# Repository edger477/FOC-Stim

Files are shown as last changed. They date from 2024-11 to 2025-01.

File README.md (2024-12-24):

FOC-Stim is an implementation of the [Restim](https://github.com/diglet48/restim) threephase signal generation algorithm
for the [B-G431B-ESC1](https://www.st.com/en/evaluation-tools/b-g431b-esc1.html) electronic speed controller.

FOC stands for Field Oriented Control, an algorithm for controlling motors, referencing the intended purpose of the hardware.

It utilizes MRAC (model reference adaptive control) to generate consistent current-controlled waveforms
as environment conditions change.

Powered by SimpleFOC.

# Hardware setup

BOM:

* B-G431B-ESC1
* USB cable
* 12v power supply (0.5A minimum)
* 3x transformer (XICON 42TU200-RC suggested)
* 3x inductor (220µH, 1A)
* 3x ceramic caps (10µF 50v)

When selecting an inductor, look for saturation current about 1A and flat inductance-current curve in the datasheet. Some options:
* KEMET SBCP-11HY221H. 80HY or 14HY series also a possibility.
* Fastron 09HVP or 09HCP series.
* Coilcraft RFB0810 or RFB1010 or RFS1317 series
* Coilcraft DR0608-224L, usable if cramped for space

A panel-mount USB micro-B is useful if you want to make this into a nice box.
[USB Micro-B](https://www.sparkfun.com/products/15464)
or [USB B](https://www.sparkfun.com/products/15463).

How to wire:

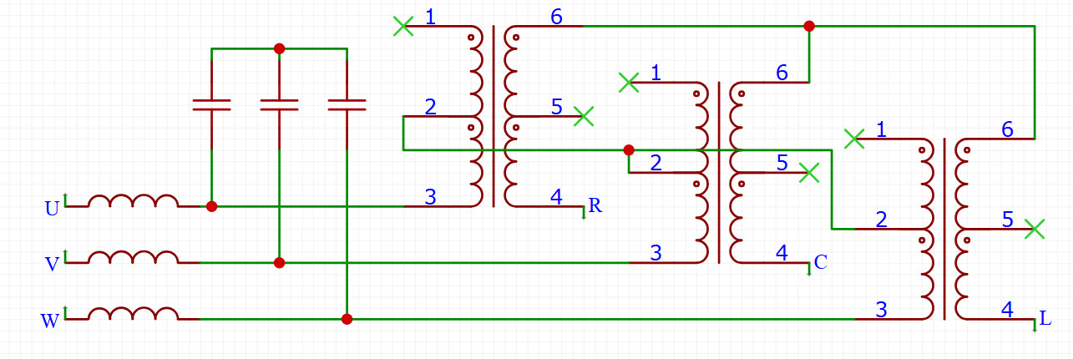
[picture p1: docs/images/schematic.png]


`U`, `V`, `W` are the 3 outputs on the board, with `U` being the one closest to the potentiometer.

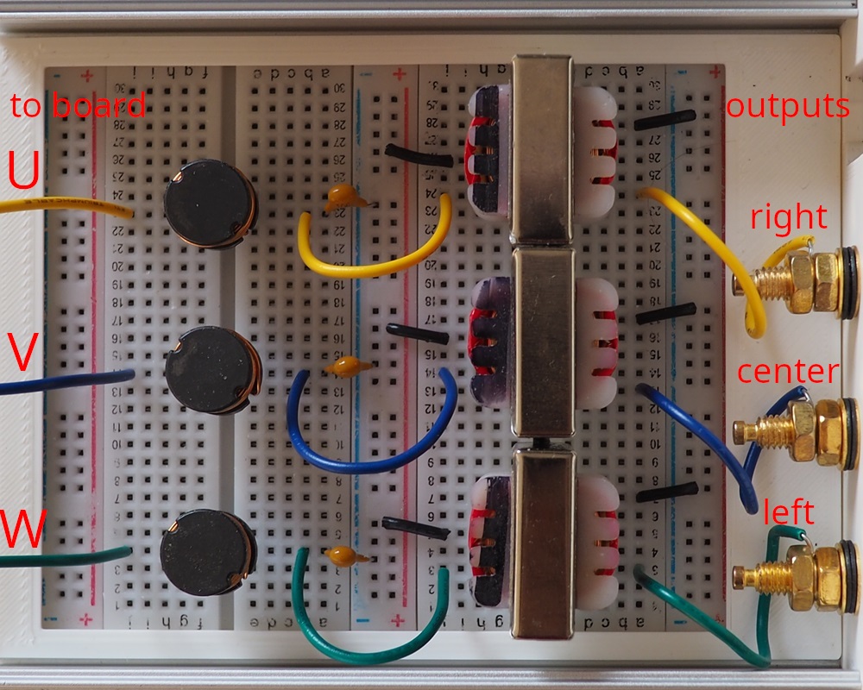
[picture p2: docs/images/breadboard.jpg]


# Software setup

From the factory, the board has a very old ST-link firmware that prevents the usb-serial from working
correctly on some computers. It is highly recommended to update the ST-link firmware using
[STM32CubeProgrammer](https://www.st.com/en/development-tools/stm32cubeprog.html) before proceeding.

Install Visual Studio Code with plugins `platformio` and `teleplot`,
then build and upload the firmware, instructions below.

Inspect `FOC-Stim/src/config.h` to configure the current limits.

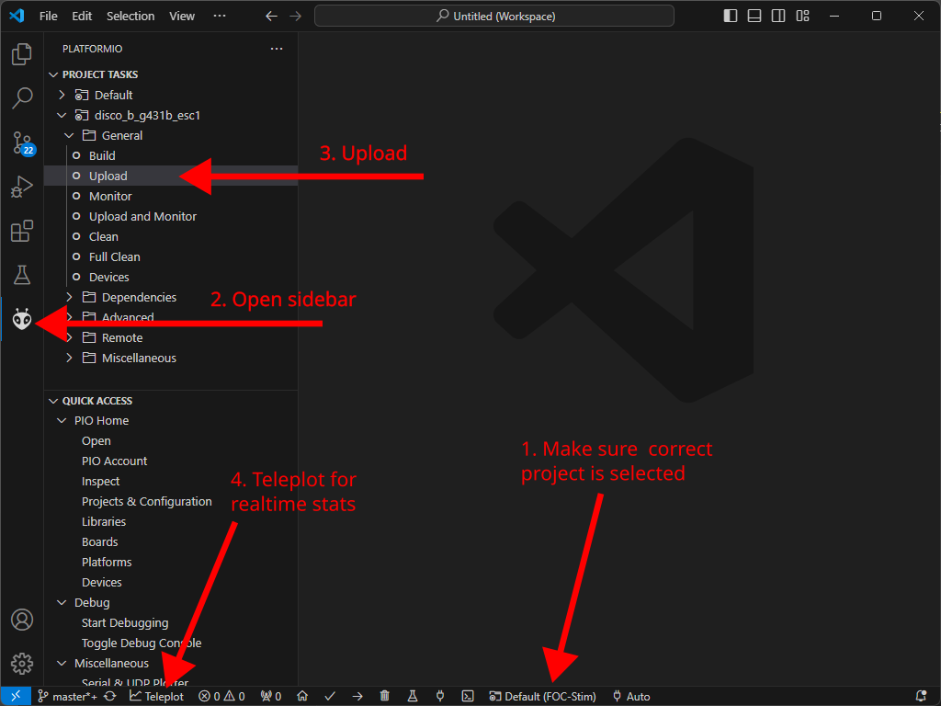
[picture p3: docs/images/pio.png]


# Control

Control over serial with Restim.

View live stats with teleplot.

The onboard pot can be used to control the signal intensity.
If you only want to use software control, turn it all the way clockwise.
You can desolder the pot and use the pins to wire an external pot for your box.

All restim features are supported except: vibration.

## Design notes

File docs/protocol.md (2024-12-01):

Not finalized.

# Signal generation parameters

FOC-Stim uses the [T-Code](https://github.com/multiaxis/TCode-Specification) protocol for receiving commands. See source code for available axis and ranges.

# Boot process

Once the device is ready to accept commands, it will print `"Device ready. Awaiting DSTART.\r\n"`.

Send `DSTART` to start pulse generation, `DSTOP` to stop.

Version string can be received with `D0`. It is highly recommended to check for an exact version string.

# Logs

The device will regularly send metrics, for example electrode resistance or device temperature information. Logs start with `$` and end with a newline. Example logline `$R_a:1.5 R_b:2.0 V_BUS:42\r\n`.

If an error occurs, unformatted debug information is printed. Errors can only be recovered by restarting the device.

These metrics are defined:

* `R_neutral`, `R_left`, `R_right`: estimated circuit resistance in ohm. Subtract the inductor and transformer resistance and multipy with the square of the winding ratio to get the skin resistance.
* `L`: estimated inductance in µH.
* `rms_neutral`, `rms_left`, `rms_right`: RMS current. Divide by the winding ratio to get the RMS current delivered to the skin.
* `V_bus`: power supply input voltage.
* `V_drive`: actual voltage used to drive the circuit. Limited to about 80% of `V_bus`.
* `F_pulse`: actual pulse frequency.
* `F_mrac`:  control frequency.
* `temp`: temperature of the onboard NTC in degrees celsius.

# Keepalive

The device will stop generating pulses if no valid commands have been received for some time. Spam `DPING` or any other valid command to subvert.

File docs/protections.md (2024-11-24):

The following protections are implemented:

* Input over/under voltage protection, shuts off the signal 
if power supply malfunctions.
* Over-current protection, shuts off signal generation if any 
of the current sensors detect current above the configured limits.

The following are ideas, not current implemented:

* Watchdog timer.
* Board temperature.
* Electrode disconnect.

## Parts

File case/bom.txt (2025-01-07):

protoboard 8cmx2cm: https://www.amazon.de/-/en/gp/product/B0BB2GS422
dc socket 5.5x2.1: https://www.amazon.de/gp/product/B09PD6J4BN/
3.5mm socket: https://www.amazon.de/-/en/gp/product/B097JHNTC7
Capacitor 1000-2000 uF 25+v
usb-c to micro usb adapter that reaches great into the box: https://www.amazon.de/-/en/gp/product/B0B7RMFMN4/

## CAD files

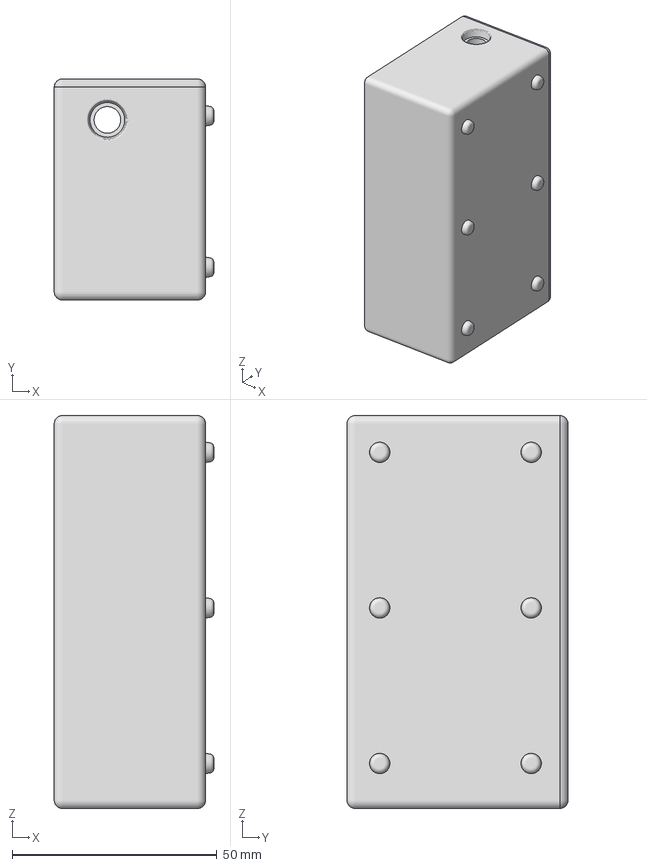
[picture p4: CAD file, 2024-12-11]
case/FOC-stim case v8.3mf
39.0 x 54.0 x 96.0 mm

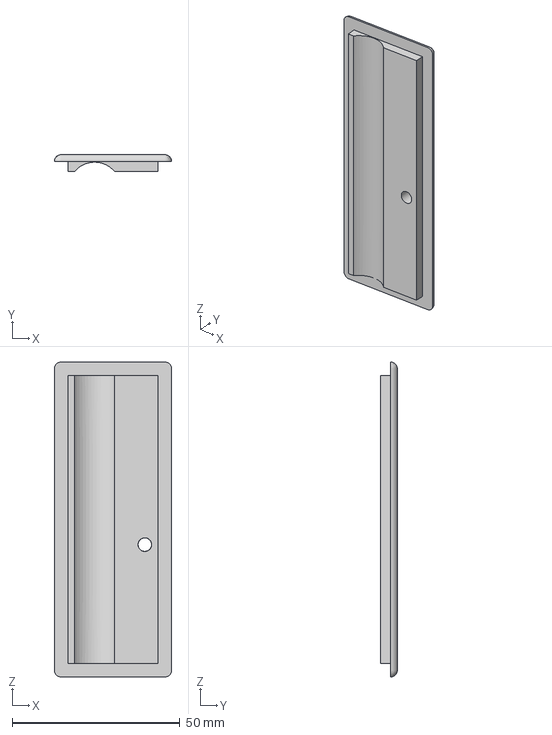
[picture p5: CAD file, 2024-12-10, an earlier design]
case/FOC-stim case v7.3mf
35.0 x 5.00 x 94.0 mm

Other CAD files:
case/FOC-stim case v7.f3d
case/FOC-stim case v8.f3d

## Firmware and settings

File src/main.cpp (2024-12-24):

#include <Arduino.h>
#include <SimpleFOC.h>

#include "tcode.h"
#include "utils.h"
#include "stim_clock.h"
#include "pulse/threephase_pulse_buffer.h"
#include "mrac_threephase_star.h"
#include "threephase_driver.h"
#include "config.h"
#include "emergency_stop.h"
#include "trace.h"

BLDCDriver6PWM bldc_driver = BLDCDriver6PWM(A_PHASE_UH, A_PHASE_UL, A_PHASE_VH, A_PHASE_VL, A_PHASE_WH, A_PHASE_WL);
// Gain calculation shown at https://community.simplefoc.com/t/b-g431b-esc1-current-control/521/21
LowsideCurrentSense currentSense = LowsideCurrentSense(0.003f, -64.0f / 7.0f, A_OP1_OUT, A_OP2_OUT, A_OP3_OUT);

MRACThreephaseStar mrac{};
ThreephasePulseBuffer pulse_threephase{};
Trace trace{};
ThreePhaseDriver threephase_driver{};

EmergencyStop emergencyStop{};

static bool status_booted = false;
static bool status_vbus = false;
static bool status_estop = false;
static bool status_playing = false;

static Clock keepalive_clock{};


void print_status() {
    uint32_t status =
        (status_booted << 0)
        | (status_vbus << 1)
        | (status_estop << 2)
        | (status_playing << 3);
    Serial.printf("status: %lu\r\n", status);
}


void tcode_D0() {
    Serial.println();
    Serial.printf("version: FOC-Stim 0.4\r\n");
    print_status();
}

void tcode_DSTART() {
    if (status_vbus && !status_playing) {
        Serial.printf("Pulse generation started\r\n");
        status_playing = true;
    }
}

void tcode_DSTOP() {
    if (status_vbus && status_playing) {
        Serial.printf("Pulse generation stopped\r\n");
        status_playing = false;
    }
}

void tcode_DPING() {
    keepalive_clock.reset();
}

struct
{
    TCodeAxis alpha{"L0", 0, -1, 1};
    TCodeAxis beta{"L1", 0, -1, 1};
    TCodeAxis volume{"V0", 0, 0, TCODE_MAX_CURRENT};
    TCodeAxis carrier_frequency{"A0", 800, 500, 1500};
    TCodeAxis pulse_frequency{"A1", 50, 1, 100};
    TCodeAxis pulse_width{"A2", 6, 3, 20};
    TCodeAxis pulse_rise{"A3", 5, 2, 10};
    TCodeAxis pulse_interval_random{"A4", 0, 0, 1};
    TCodeAxis calib_center{"C0", 0, -10, 10};
    TCodeAxis calib_ud{"C1", 0, -10, 10};
    TCodeAxis calib_lr{"C2", 0, -10, 10};
} axes;
struct {
    TCodeDeviceCommand d0{"0", &tcode_D0};
    TCodeDeviceCommand d_start{"START", &tcode_DSTART};
    TCodeDeviceCommand d_stop{"STOP", &tcode_DSTOP};
    TCodeDeviceCommand d_ping{"PING", &tcode_DPING};
} tcode_device_commands;
TCode tcode(reinterpret_cast<TCodeAxis *>(&axes), sizeof(axes) / sizeof(TCodeAxis),
            reinterpret_cast<TCodeDeviceCommand *>(&tcode_device_commands), sizeof(tcode_device_commands) / sizeof(TCodeDeviceCommand));

void estop_triggered()
{
    mrac.print_debug_stats();
    trace.print_mainloop_trace();
}

void setup()
{
    // use monitoring with serial
    Serial.begin(115200);
    Serial.println("- begin setup");
    // enable more verbose output for debugging
    // comment out if not needed
    // SimpleFOCDebug::enable(&Serial);

    // print status to let the computer know we have rebooted.
    print_status();

    Serial.println("- init driver");
    bldc_driver.voltage_power_supply = STIM_PSU_VOLTAGE;
    bldc_driver.pwm_frequency = STIM_PWM_FREQ;
    bldc_driver.init();

    Serial.println("- init emergency stop");
    emergencyStop.init(&bldc_driver, &currentSense, &estop_triggered);

    Serial.println("- init current sense");
    currentSense.linkDriver(&bldc_driver);
    int current_sense_err = currentSense.init();
    if (current_sense_err != 1)
    {
        Serial.println("- init current sense failed!");
        emergencyStop.trigger_emergency_stop();
        while (1)
        {
        }
    }
    bldc_driver.enable();

    threephase_driver.init(&bldc_driver, &currentSense);

    Serial.printf("- init mrac\r\n");
    mrac.init(&threephase_driver, &currentSense, &emergencyStop);

    status_booted = true;
    float vbus = read_vbus(&currentSense);
    if (vbus > STIM_PSU_VOLTAGE_MIN) {
        status_vbus = true;
    }
    print_status();
}

void loop()
{
    static Clock total_pulse_length_timer;
    static float pulse_total_duration = 0;
    static Clock actual_pulse_frequency_clock;
    static Clock rms_current_clock;
    static Clock status_print_clock;
    static Clock vbus_print_clock;
    static Clock vbus_high_clock;
    static uint32_t pulse_counter = 0;
    static float actual_pulse_frequency = 0;

    // do comms
    bool dirty = tcode.update_from_serial();

    // safety checks
    emergencyStop.check_temperature();
    emergencyStop.check_vbus_overvoltage();
    emergencyStop.check_current_limits();   // not really needed since all phases connected to ground at this point.

    // check vbus, stop playing if vbus is too low.
    float vbus = read_vbus(&currentSense);
    if (vbus < STIM_PSU_VOLTAGE_MIN) {
        vbus_high_clock.reset();

        // vbus changed high->low.
        if (status_vbus) {
            read_vbus(&currentSense);
            status_vbus = false;
            status_playing = false;
            Serial.printf("V_BUS under-voltage detected (V_BUS = %.2f). Stopping pulse generation.\r\n", vbus);
            print_status();
            vbus_print_clock.reset();
        }

        // print something if vbus has been low for a while to alert user they should flip power switch on the device.
        vbus_print_clock.step();
        if (vbus_print_clock.time_seconds > 4) {
            vbus_print_clock.reset();
            Serial.printf("V_BUS too low: %.2f\r\n", vbus);
        }
    } else {
        // if vbus is high and stable
        if (!status_vbus && vbus_high_clock.time_seconds > 0.2f) {
            Serial.printf("V_BUS online. V_BUS: %.2f\r\n", vbus);
            status_vbus = true;
            status_playing = false;
            print_status();
        }
        vbus_high_clock.step();
    }

    // keepalive timer. Stop playing if no messages have been received for some time.
    if (dirty) {
        keepalive_clock.reset();
    }
    keepalive_clock.step();
    if (keepalive_clock.time_seconds > 2 && status_playing) {
        Serial.println("Connection lost? Stopping pulse generation.");
        status_playing = false;
        print_status();
    }

    // correct for drift in the current sense circuit
    threephase_driver.adjust_offsets();

    // DSTART / DSTOP
    if (! status_playing) {
        delay(10);
        return;
    }

    // stall out idle portion of the pulse
    total_pulse_length_timer.step();
    if (total_pulse_length_timer.time_seconds <= pulse_total_duration) {
        return;
    }

    // ready to generate next pulse!
    MainLoopTraceLine *traceline = trace.next_main_loop_line();
    total_pulse_length_timer.reset();
    traceline->t_start = total_pulse_length_timer.last_update_time;

    // calculate stats
    pulse_counter++;
    actual_pulse_frequency_clock.step();
    actual_pulse_frequency = lerp(.05f, actual_pulse_frequency, 1e6f / actual_pulse_frequency_clock.dt_micros);

    // get all the pulse parameters
    uint32_t t0 = micros();
    float pulse_alpha = axes.alpha.get_remap(t0);
    float pulse_beta = axes.beta.get_remap(t0);
    float pulse_amplitude = axes.volume.get_remap(t0); // pulse amplitude in amps
    float pulse_carrier_frequency = axes.carrier_frequency.get_remap(t0);
    float pulse_frequency = axes.pulse_frequency.get_remap(t0);
    float pulse_width = axes.pulse_width.get_remap(t0);
    float pulse_rise = axes.pulse_rise.get_remap(t0);
    float pulse_interval_random = axes.pulse_interval_random.get_remap(t0);

    float calibration_center = axes.calib_center.get_remap(t0);
    float calibration_lr = axes.calib_lr.get_remap(t0);
    float calibration_ud = axes.calib_ud.get_remap(t0);

    float pulse_active_duration = pulse_width / pulse_carrier_frequency;
    float pulse_pause_duration = max(0.f, 1 / pulse_frequency - pulse_active_duration);
    pulse_pause_duration *= float_rand(1 - pulse_interval_random, 1 + pulse_interval_random);
    pulse_total_duration = pulse_active_duration + pulse_pause_duration;

    // mix in potmeter
    float potmeter_voltage = read_potentiometer(&currentSense);
    float potmeter_value = inverse_lerp(potmeter_voltage, POTMETER_ZERO_PERCENT_VOLTAGE, POTMETER_HUNDRED_PERCENT_VOLTAGE);
    pulse_amplitude *= potmeter_value;

    // pre-compute the new pulse
    pulse_threephase.create_pulse(
        pulse_amplitude,
        pulse_alpha,
        pulse_beta,
        pulse_carrier_frequency,
        pulse_width,
        pulse_rise,
        calibration_center,
        calibration_ud,
        calibration_lr);

    // store stats
    traceline->amplitude = pulse_amplitude;
    total_pulse_length_timer.step();
    traceline->dt_compute = total_pulse_length_timer.dt_micros;

    // play the pulse
    mrac.play_pulse(&pulse_threephase);
    total_pulse_length_timer.step();

    // store stats
    Clock stats_timer;
    traceline->dt_play = total_pulse_length_timer.dt_micros;

    traceline->skipped_update_steps = mrac.skipped_update_steps;
    traceline->v_drive_max = mrac.v_drive_max;
    traceline->max_recorded_current_neutral = mrac.current_max_neutral;
    traceline->max_recorded_current_left = mrac.current_max_left;
    traceline->max_recorded_current_right = mrac.current_max_right;

    traceline->R_neutral = mrac.estimate_resistance_neutral();
    traceline->R_left = mrac.estimate_resistance_left();
    traceline->R_right = mrac.estimate_resistance_right();
    traceline->L = mrac.estimate_inductance();

    // occasionally print some stats..
    if ((pulse_counter + 0) % 10 == 0)
    {
        Serial.print("$");
        Serial.printf("R_neutral:%.2f ", mrac.estimate_resistance_neutral());
        Serial.printf("R_left:%.2f ", mrac.estimate_resistance_left());
        Serial.printf("R_right:%.2f ", mrac.estimate_resistance_right());
        Serial.printf("L:%.2f ", mrac.estimate_inductance() * 1e6f);
        Serial.println();
    }
    if ((pulse_counter + 2) % 10 == 0)
    {
        Serial.print("$");
        Serial.printf("V_drive:%.2f ", mrac.v_drive_max);
        Serial.printf("I_max_a:%f ", abs(mrac.current_max_neutral));
        Serial.printf("I_max_b:%f ", abs(mrac.current_max_left));
        Serial.printf("I_max_c:%f ", abs(mrac.current_max_right));
        Serial.println();
        mrac.v_drive_max = 0;
        mrac.current_max_neutral = 0;
        mrac.current_max_left = 0;
        mrac.current_max_right = 0;
    }
    if ((pulse_counter + 4) % 10 == 0)
    {

    }
    if ((pulse_counter + 6) % 10 == 0)
    {   
        rms_current_clock.step();
        Serial.print("$");
        Serial.printf("rms_neutral:%f ", sqrtf(mrac.current_squared_neutral / rms_current_clock.dt_seconds));
        Serial.printf("rms_left:%f ", sqrtf(mrac.current_squared_left / rms_current_clock.dt_seconds));
        Serial.printf("rms_right:%f ", sqrtf(mrac.current_squared_right / rms_current_clock.dt_seconds));
        Serial.println();
        mrac.current_squared_neutral = 0;
        mrac.current_squared_left = 0;
        mrac.current_squared_right = 0;
    }
    if ((pulse_counter + 8) % 20 == 0)
    {
        Serial.print("$");
        Serial.printf("V_BUS:%.2f ", read_vbus(&currentSense));
        Serial.printf("temp:%.1f ", read_temperature(&currentSense));
        Serial.printf("F_pulse:%.1f ", actual_pulse_frequency);
        Serial.printf("model_steps:%i ", mrac.pwm_write_index);
        Serial.printf("model_skips:%i ", mrac.skipped_update_steps);
        Serial.printf("pot:%f ", potmeter_value);
        Serial.println();
    }

    stats_timer.step();
    traceline->dt_logs = stats_timer.dt_micros;
}

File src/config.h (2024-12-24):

#ifndef FOCSTIM_CONFIG_H
#define FOCSTIM_CONFIG_H

// current limits
#define TCODE_MAX_CURRENT 1.0f                          // in amps
#define ESTOP_CURRENT_LIMIT (TCODE_MAX_CURRENT + 0.20f) // Needs about .20f to account for measurement noise.

// board temperature limits
#define MAXIMUM_TEMPERATURE 80.f    // degrees celsius.

// supply voltage and pwm
#define STIM_PWM_FREQ 38000 // switching frequency is twice this frequency
#define STIM_PSU_VOLTAGE 12.0f
#define STIM_PSU_VOLTAGE_MIN 11.5f // e-stop if exceeded
#define STIM_PSU_VOLTAGE_MAX 13.5f // e-stop if exceeded
#define STIM_PWM_MINIMUM_OFF_TIME 4e-6f // limited by pwm-rejection of current sense. Experimentally determined to be 3.15us.
#define STIM_PWM_MAX_DUTY_CYCLE float(1 - STIM_PWM_MINIMUM_OFF_TIME * STIM_PWM_FREQ)

// potentiometer volume control
#define POTMETER_ZERO_PERCENT_VOLTAGE      3.3f
#define POTMETER_HUNDRED_PERCENT_VOLTAGE   0.0f

// initial conditions and limits for the model
#define MODEL_RESISTANCE_INIT 2.0f
#define MODEL_RESISTANCE_MIN 1.0f
#define MODEL_RESISTANCE_MAX 15.0f
#define MODEL_INDUCTANCE_INIT 450e-6f
#define MODEL_INDUCTANCE_MIN 100e-6f
#define MODEL_INDUCTANCE_MAX 1500e-6f

// size of precomputed pulse buffer
#define THREEPHASE_PULSE_BUFFER_SIZE 256
#define ONEPHASE_PULSE_BUFFER_SIZE 256

// enable for nicer looking waveforms on the scope. Not safe for humans!
// #define THREEPHASE_PULSE_DEFEAT_RANDOMIZATION

#endif // FOCSTIM_CONFIG_H

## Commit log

2024-11-21 Fix limit maximum duty cycle.
    [config.h, mrac_threephase_star.cpp]
2024-11-21 Increase max voltage because it seems to read a bit high on some boards.
2024-11-21 Log all 3 phase currents in emergency stop.
2024-11-21 Increase I in PID by factor of 25000.
2024-11-21 Refactor to avoid power-of-2 requirement.
2024-11-22 Implement tcode device commands, startup sequence
2024-11-24 Adjust PID control for better readability.
2024-11-27 Add panel mount USB micro-B to BOM
2024-11-27 Flip left/right signal. I got this wrong due to a bug in restim.
    [main.cpp]
2024-11-27 Add schematic.
2024-11-28 Reverse left/right calibration.
2024-11-30 Adjust MRAC model, faster convergance, less noise, reduced drift.
    [main.cpp, mrac_threephase_star.cpp, mrac_threephase_star.h]
2024-12-01 Implement temperature protection
2024-12-01 Add rms current metrics, remove some of the other metrics
2024-12-04 Improve comms handling and power consumption during pulse pause.
    When pwm is (0, 0, 0), all phases connected to ground and no switching
    occurs, reducing power consumption by about 0.6w * (1 - duty_cycle)
2024-12-10 added case 3dprint cad files
    [FOC-stim case v7.3mf, FOC-stim case v7.f3d]
2024-12-10 Allow device to recover from under-voltage. Bump version to 0.3.
2024-12-11 added version of cases that are 1mm thicker (better printing)
    [FOC-stim case v8.3mf, FOC-stim case v8.f3d]
2024-12-18 Fix typo in clock variable name.
    [main.cpp]
2024-12-18 Bump to 0.4, expand frequency range to 500-1500hz, increase max current to 1A
    With default tau=355us, max current at 800hz is 0.76A down from 0.8A.
    Other changes:
    - Move to interrupt-based control with exact timings.
    - Reduce PWM frequency from 40khz to 38khz to meet timer deadlines.
    - Implement current sense offset drift correction.
    - Refactor out some simpleFOC code to threephase_driver.h
    - Rename threephase pulse class.
    [config.h, emergency_stop.cpp, main.cpp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]
